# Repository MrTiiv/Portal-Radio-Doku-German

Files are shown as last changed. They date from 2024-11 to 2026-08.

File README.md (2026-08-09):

# Funktionierendes Portal Radio (Remix von [@AIBot | MyMiniFactory](https://www.myminifactory.com/object/3d-print-portal-radio-50006) (GERMAN)

## Vorwort
Zunächst ein Dank an:
- @Aibot für die Druckdateien
- [**@Astro_Flora**](https://github.com/fh190) für das Drucken von “Shell” und “Bottom” mit seinem Bambu Lab X1C 
- @monion für das Helfen mit dem Code (er ist nicht verantwortlich für den endgültigen Code ;D )
- @Chair Gaming für allgemeine Hilfe

**Hinweis: 
Hier kannst du nur meine modifizierten Teile herunterladen. Bitte lade das komplette Projekt vom Original-Autor herunter! 
[**https://www.myminifactory.com/object/3d-print-portal-radio-50006**](https://www.myminifactory.com/object/3d-print-portal-radio-50006)**
  
## Allgemeine Informationen  
Für die Elektronik habe ich mich an einer Anleitung für ein DIY-Radio von AZ-Delivery orientiert und es so angepasst, wie es für mich passt: [https://www.az-delivery.de/products/internet-radio-mit-dem-esp32](https://www.az-delivery.de/products/internet-radio-mit-dem-esp32).

Verwendete Drucker:

-   **Bambu Lab X1C und Bambu Lab A1 Mini**
-   „Shell“ und „Base“ wurden mit dem Bambu Lab X1C gedruckt, können aber auch mit dem Bambu Lab A1 gedruckt werden. Beide haben eine Druckfläche von 256x256x256 mm.
-   Kleinere Teile wurden mit dem Bambu Lab A1 Mini (Druckfläche 180x180x180 mm) gedruckt.

### Bekannte Probleme
Da dies mein erstes Projekt ist, kenne ich mich mit der verwendeten Mikroelektronik noch wenig aus. 
Ein nerviges Problem ist der DFPlayer. 
~~Beim Einschalten gibt er ein Störgeräusch von sich, bevor er den Song abspielt. Auch während des Songs ist ein leises, aber hörbares Störgeräusch vorhanden, insbesondere bei geringer Lautstärke. Bis jetzt habe ich dafür noch keine Lösung gefunden.~~
Das DFPlayer Problem wurde gelöst, die Verbindung vom PAM zum DFPlayer muss ein geschrimtes Kabel sein, damit sind die Störgeräusche um einiges leiser

~~Dreht man den Verstärker PAM8403 bis ganz an Ende zu dem Rastpunkt und wieder zurück Startet der Arduino aus unbekannten Gründen neu. Ich habe das Problem bisher noch nicht behoben und habe bisher auch noch keinen Lösungsansatz.~~
~~Das Problem mit dem Absturz ist behoben. Ich habe Kondensatoren hinzugefügt, einmal auf Plus und einmal auf Minus (siehe Schaltplan), damit ist das Problem im Augenblick behoben.~~
Die Abstürze wurden alle behoben beim entfernen des Step Up Moduls und des Kleinen Akkus, eine Powerbank hat das ganze Problem gelöst. 

## Das Portal Radio
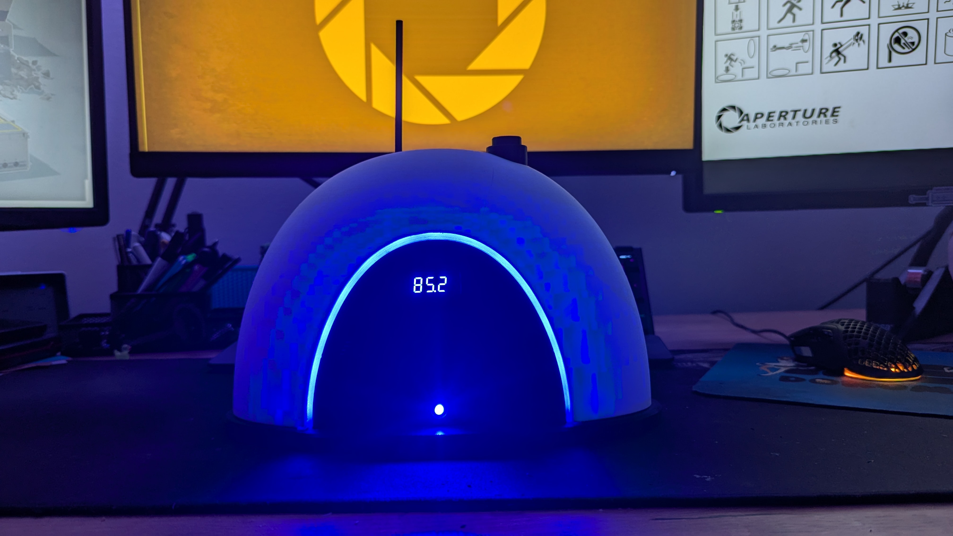
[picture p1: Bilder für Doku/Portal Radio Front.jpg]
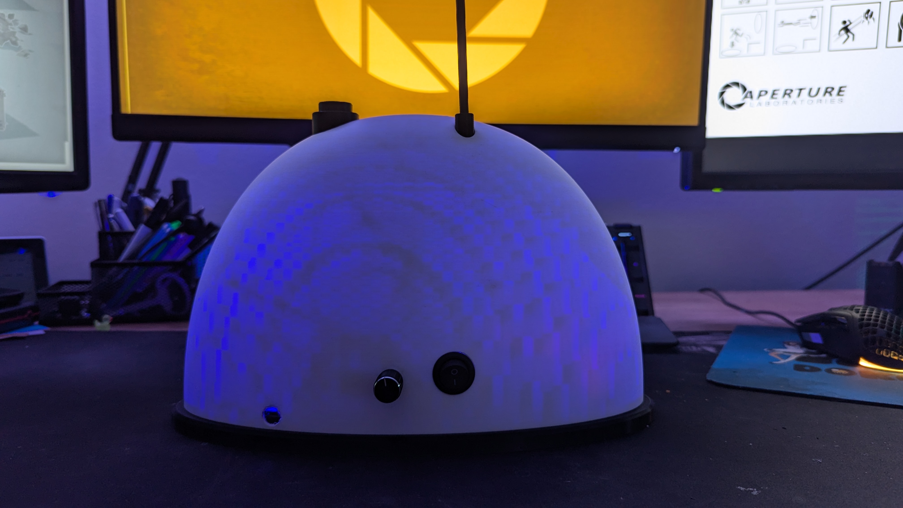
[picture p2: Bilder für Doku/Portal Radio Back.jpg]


### Funktion
  
Das Radio hat folgende Funktionen:

-   Beim Einschalten leuchten die LEDs am Ring blau auf, die 7-Segment-Anzeige zeigt eine Startup Animation und ein Startup Sound ist zu hören
-   Nach dem Einschalten leuchtet die blaue LED an der Front als Indikatior das die Musik abgespielt wird.
-   Beim Betätigen des Potis blinkt die blaue LED an der Front und es kann mithilfe des Potis eine neue "Frequenz" eingestellt werden die beim erneuten betätigen des Potis bestätigt wird.
-   Über den Drehregler oben kann die Lautstärke eingestellt werden.
  
### Teileliste
  
Hier sind die Teile, die ich für das Radio gekauft habe, eine Mischung vom Amazon und AliExpress:  
  
- [7 Segment Anzeige TM1637 Blau](https://www.amazon.de/dp/B09X1Z8CC8?ref=ppx_yo2ov_dt_b_fed_asin_title)  
- [USB Typ C Batterielademodul TP4056](https://amzn.eu/d/bJx8FN1) [¹]
- [AZ Delivery Mikrocontroller AZ-ATmega 328](https://amzn.eu/d/12fmeU2)  
- [2x AZ Delivery DFPlayer Mini 3 Watt Lautsprecher](https://amzn.eu/d/aCnC54G)  
- [5mm LED Blau](https://amzn.eu/d/fTzluys)  
- [DFPlayer Mini](https://de.aliexpress.com/item/1005006181511315.html?)  
- [PAM8403 Audio Verstärker](https://de.aliexpress.com/item/1005006135778016.html)  
- [JST XH 2 Polig Kabelstecker](https://de.aliexpress.com/item/1005006577211209.html) [²] 
- [Wippschalter Rund](https://amzn.eu/d/0qvCGKB)  
- [verwendeter Akku](https://amzn.eu/d/0gAyQbPa) 
- [~350g PLA Schwarzes Filament](https://amzn.eu/d/ibRLTVA)
- [~265g PLA Weißes Filament](https://amzn.eu/d/6HExSpr)
- [~30g PLA Durchsichtiges Filament](https://amzn.eu/d/5HmzEyD)
 -[~2g PETG Schwarzes Filament](https://amzn.eu/d/5IXwTd8)[⁴]
- Sekundenkleber (zum Ankleben der Elektronik so wie der LED's)
- Blechschrauben (zum Anschrauben der Elektronik)

[¹]: Vorsicht! mit diesem Lademodul kann man nur mit einem USB A auf USB C Kabel laden, nicht mit einem USB C - USB C Kabel.

[²]: Um den Akku und die Lautsprecher abtrennbar zu machen, habe ich die Originalen Stecker der jeweiligen Komponenten abgeschnitten und diesen angelötet, schlauer wäre gewesen gleich den richtigen Stecker zu bestellen aber egal ^^.

[⁴]: Das PETG Filament ist für das Aperture Logo vorne am Radio damit man es sieht. Man sieht es mit dem PETG Filament zwar, es kommt aber tatsächlich darauf an wie man draufschaut. Auffällig ist es nicht, also kann man dafür auch anderes Filament z.b. in einer anderen Farbe verwenden.

## 3D Druck 

### Info und Änderungen
Abgeändert habe ich das *"[front-panel](https://github.com/MrTiiv/Portal-Radio-Doku-German/blob/main/Modified%203D%20Print%20Parts/front-panel-modified-for-displayl.stl)"* damit das Display vorne reinpasst so wie den *"[top-button](https://github.com/MrTiiv/Portal-Radio-Doku-German/blob/main/Modified%203D%20Print%20Parts/top-button-modified-for-PAM8403.stl)"* damit man den Knopf oben für die Lautstärke drehen kann und das der Audio Verstärker PAM8403 da Perfekt hineinpasst. Diese Änderungen kannst du hier auf GitHub herunterladen. 
Dadurch dass ich das Display in das Radio montiert habe müssen folgende Teile die du von Aibot auf MMF herunterlädst nicht gedruckt werden:
- "ledholder-screen"
- "screen-main"
- "screen-8-top"
- "screen-8-bot"

Außerdem habe ich "electronics-mount" und "front-logo-stencil-1" nicht gedruckt. Das Front Logo habe ich so angepasst, das der Drucker das Logo mit vorne rein druckt. Aibot hat denke ich vorgesehen das man das Logo vorne Draufsprüht mit dem "front-logo-stencil-1".

### Druckereinstellungen
Die Druckeinstellungen basieren alle auf **Bambu Studio**.

-   **0,20 mm Standardprofil**, 15 % Fülldichte, Gitternetz-Füllmuster, Wandlinien: 2, Schichthöhe: 0,2 mm, keine Supports (außer für „Shell“).
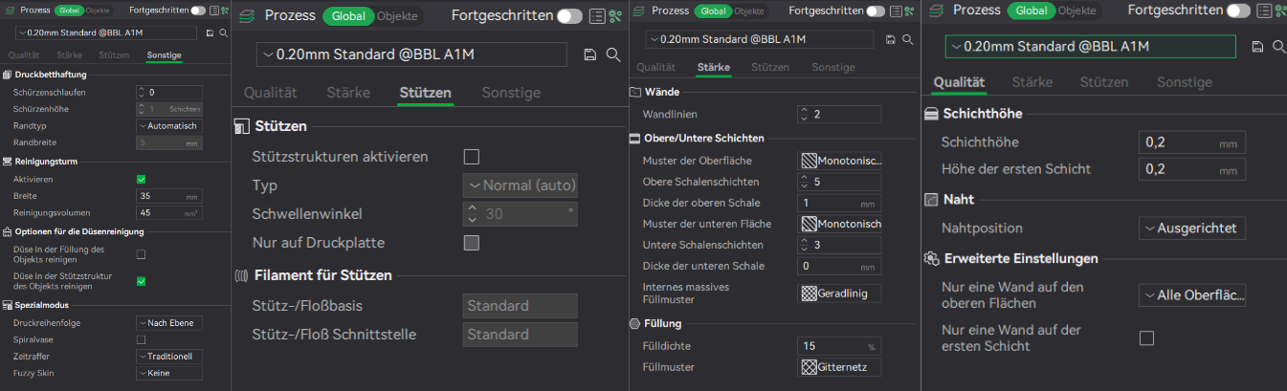
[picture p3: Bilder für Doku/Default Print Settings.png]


### Base

Für die Base habe ich "base" genommen und nicht "base-with-holes-for-electronics-mount" da ich meine eigene Elektronik eingebaut habe.
Folgende Druckeinstellungen habe ich bei der Base geändert:

- Fülldichte: 35 %, Füllmuster: Geradlinig, Wandlinien: 4 (für besseren Halt der Schrauben). 

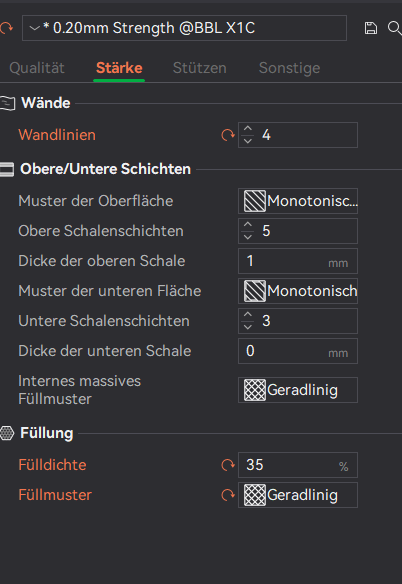
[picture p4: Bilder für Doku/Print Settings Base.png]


### Shell
Die Shell muss mit Supports gedruckt werden. Verwendet wurden die Supports "Baum". 
Bei der Druckbetthaftung habe ich die Schürzenschlaufen auf 5 und die Nahtposition auf zufällig. 

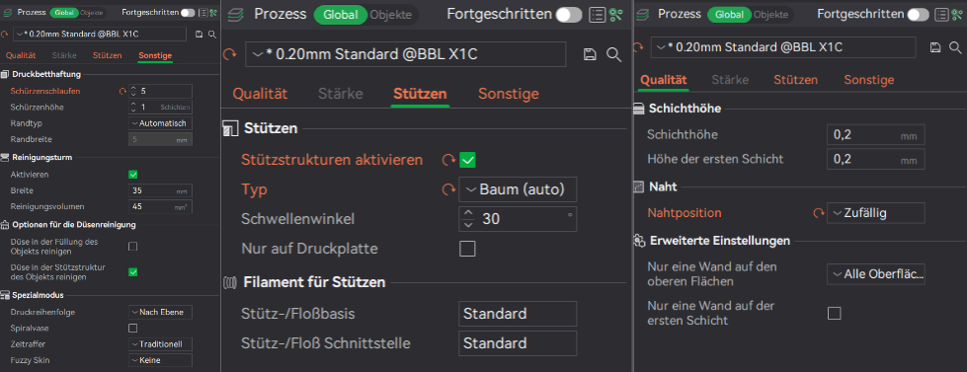
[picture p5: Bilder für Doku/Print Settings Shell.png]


### Zusammenbau
Nachdem alles gedruckt wurde sollte man 10 einzelne Teile vor sich liegen haben
- "base"
- "shell"
- "antenne-holder"
- "grill-left"
- "grill-right"
- "led-ark"
- "led-ark-diffuser"
- "led-ring"
- "[front-panel](https://github.com/MrTiiv/Portal-Radio-Doku-German/blob/main/Modified%203D%20Print%20Parts/front-panel-modified-for-displayl.stl)" (meine geänderte Version)
- "[top-button](https://github.com/MrTiiv/Portal-Radio-Doku-German/blob/main/Modified%203D%20Print%20Parts/top-button-modified-for-PAM8403.stl)" (meine geänderte Version)

An sich sollte es sich fast von selber erklären wie das Radio zusammengebaut wird. 
"base" und "shell" werden miteinander verschraubt, ich habe eine M3 Mutter in die "shell" geklebt und mit einer M3x8 Schraube verbinde ich dann "base" und "shell" auch so das es einfach wieder geöffnet werden kann.

"antenne-holder" habe ich an die "shell" angeklebt

"top-button" habe ich auch an die "shell" angeklebt

"grill-left" und "grill-right" habe ich an "front-panel" angeklebt 

"led-ring" habe ich auch an "front-panel" angeklebt

"led-ark" habe ich in die dafür vorgesehenen löcher in der "base" mit Blechschrauben eingeschraubt, nachdem ich die LED's in die "led-ark" eingeklebt hatte. Ich habe nicht alle löcher vom "led-ark" mit LED's gefüllt, ich habe nur jedes zweite Loch verwendet und es ist trotzdem hell genug. Auch habe ich erst alle LED's Parallel zusammengelötet bevor ich die ark in die Base eingeschraubt habe.

Die Löcher für den ein/aus Schalter so wie das Loch für den Poti hinten und den Ladeport habe ich je nach Position in die Shell gebohrt.. 

## Die Elektronik

### Schaltplan
Wie bereits am Anfang erwähnt, habe ich die Elektronik von einer DIY Anleitung für ein Internetradio von AZ Delivery abgeschaut. Aber bevor ich die Elektronik verdrahtet und eingebaut habe, habe ich mit der Software **Fritzing** einen Schaltplan erstellt, den ich euch hier zur Verfügung stelle. 

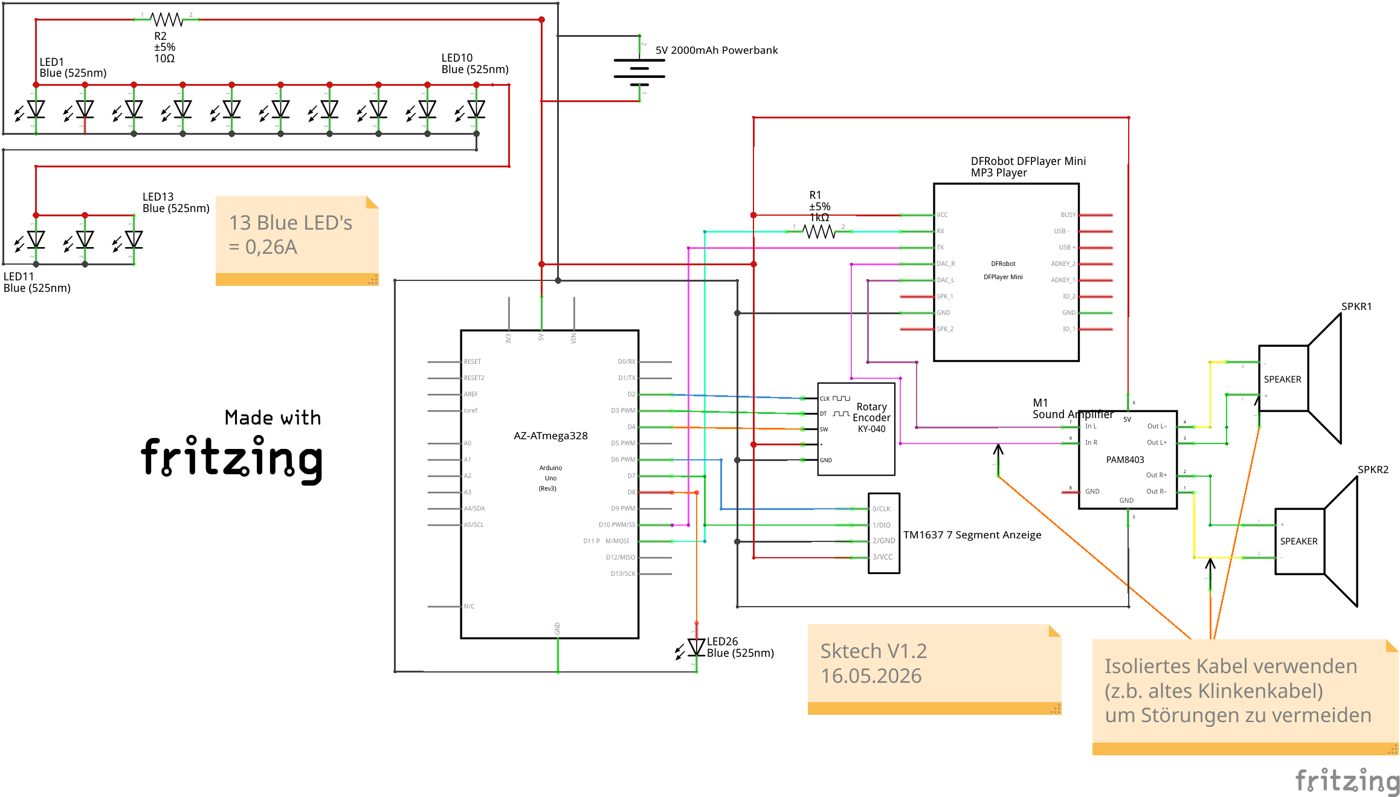
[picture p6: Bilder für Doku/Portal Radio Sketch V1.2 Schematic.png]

> VORSICHT! Bei der Programmierung des DFPlayers ist RX und TX wieso auch immer gedreht.
z.b. **`SoftwareSerial mySoftwareSerial(11, 10); // RX, TX`** funktioniert nicht du musst
 **`SoftwareSerial mySoftwareSerial(10, 11); // RX, TX`** verwenden.
Also **RX = TX** und **TX = RX** (wieso auch immer?)

Der Schaltplan ist 1:1 zu meinem jetzigen Portal Radio.
Das Step Up Module muss VOR dem einbauen eingestellt werden. Ich habe die ganze Elektronik gelötet, das Step Up Module hätte ich genauso wie den Akku und die Lautsprecher Steckbar machen sollen, falls das Modul nochmal nachgestellt werden muss. Die Spannung habe ich mit Wago 221 Klemmen verteilt, die ich auf der Base aufgeklebt habe (please don't judge me)

### Das Einbauen der Elektronik

An sich gibt es keine feste Position für die Elektronik, das muss man am Ende selbst entscheiden.

Ich habe den Charger und das Step-Up Module mit kleinen Abstandshaltern wegen den Lötpunkten an der Base mit Sekundenkleber festgeklebt.

Die LED's habe ich mit jeweils einem kleinen tropfen Sekundenkleber in den led ring geklebt.

Den Arduino habe ich auch mit einem kleinen Abstandshaltern mit Blechschrauben festgeschraubt.

Für den DFPlayer habe ich eine kleine Platte gedruckt, die etwas länger ist als der DFPlayer, um den DFPlayer mit zwei Blechschrauben zu befestigen. Die Platte hält den DFPlayer so gesehen fest.

Die 7 Segment Anzeige habe ich in das von mir geänderte Front Panel eingeschraubt.

Die Lautsprecher habe ich schräg in das Front Panel eingeschraubt damit die Membranen sogesehen durch den "grill-left" und "grill-right" hindurchschauen.

### Der Code

Dieser Code ist mein erster selber geschriebener Code für einen Arduino. Bitte teilt es mir mit falls fehler oder Optimierungen zu sehen sind.

Der Code hat folgende Funktion:

Das Radio fährt beim einschalten hoch und zeigt während des hochfahrens eine kleine Animation vorne auf der Anzeige gefolgt von einem Startup Sound.
Nachdem das hochfahren abgeschlossen ist Spielt das Radio den Standart Portal Radio Sound im loop und zeigt vorne auf der Anzeige 85.2. 
Wenn der POTI hinten am Radio betätigt wird kann eine andere "Frequenz" eingestellt werden. Wird die gewünschte Frequenz eingestellt und erneut mit dem betätigen des POTIS bestätigt Spielt das Radio einen anderen Song der vorher auf die SD Karte geladen wurde.
(Die Songs und die Nummern der Songs müssen im Code natürlich demensprechen angepasst werden. Bei der von mir Verwendeten DFPlayer Libary ist es so das die Nummer 1 der erste Song ist der auf die SDKarte geladen wurde. Nummer 2 ist der zweite Song der auf die SD Karte geladen wurde etc....)
Alles im allem ist das die Hauptaufgabe des Codes, weitere funktionen kann man sich aus den (hoffentlich verständlichen) Kommentaren des Codes entnehmen. 

AI Disclaimer:
Der Code wurde von mir  geschrieben aber AI hat mir geholfen bei den Kommentaren und bei generellen Fragen beim Schreiben des Codes.
- GitHub Copilot hat mir bei den Kommentaren geholfen
- ChatGPT hat mir beim beantworten von Fragen geholfen und bei dem Optimieren der Kommentare.
Keiner der AI Programme hat eine Zeile des Codes geschrieben.

## Schlusswort
Ich hoffe, diese Dokumentation hilft beim Nachbau des Portal Radios. Das Radio ist ein wirklicher Hingucker und das es den Radiosong abspielt, macht es noch um einiges cooler.

Fragen oder Anregungen gerne auf GitHub, Discord (MrTiiv), [Instagram](https://www.instagram.com/mrtiiv/), [Steam](https://steamcommunity.com/id/MrTiiv).

 >This was a triumph  
I'm making a note here; "Huge success"

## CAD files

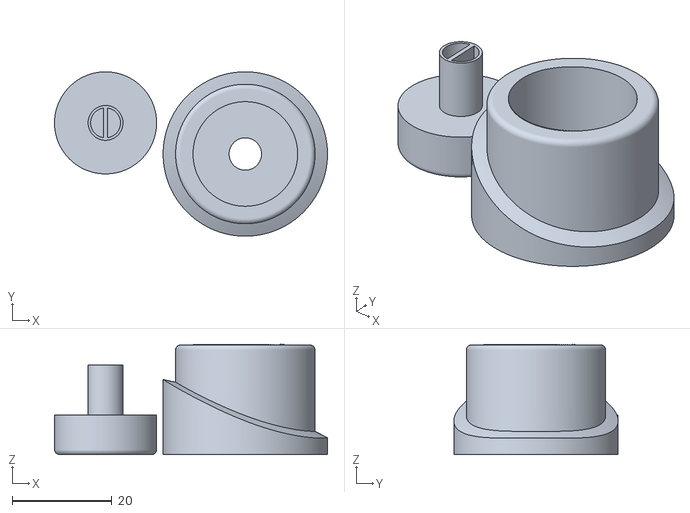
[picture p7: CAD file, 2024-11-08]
Modified 3D Print Parts/top-button-modified-for-PAM8403.stl
54.8 x 33.0 x 22.1

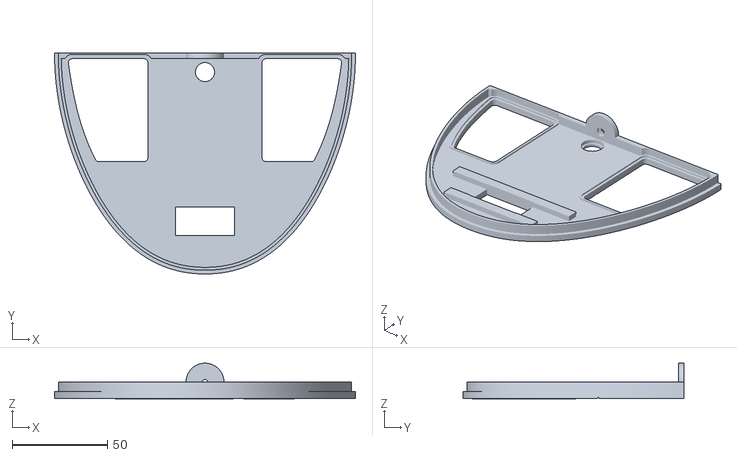
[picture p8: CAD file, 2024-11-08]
Modified 3D Print Parts/front-panel-modified-for-displayl.stl
158.0 x 116.0 x 18.7

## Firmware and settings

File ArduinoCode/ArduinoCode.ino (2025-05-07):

                                                 
 /***********************************************************************************************
 *                                                                                             *
 *    _|      _|            _|_|_|_|_|  _|  _|                                                 *
 *   _|_|  _|_|  _|  _|_|      _|              _|      _|                                      * 
 *   _|  _|  _|  _|_|          _|      _|  _|  _|      _|                                      *
 *   _|      _|  _|            _|      _|  _|    _|  _|                                        *
 *   _|      _|  _|            _|      _|  _|      _|                                          *      
 *                                                                                             *
 *                                                                                             *
 *  Project:       Working Portal Radio, plays Music from the Game                             *
 *  Author:        MrTiiv                                                                      *
 *  Year:          2025                                                                        *
 *  License:       GNU General Public License v3.0                                             *
 *                                                                                             *
 *  The corresponding circuit schematic is available on my GitHub:                             *
 *  https://github.com/MrTiiv/Portal-Radio-Doku-German                                         *
 *                                                                                             *
 *  This program is free software: you can redistribute it and/or modify                       *
 *  it under the terms of the GNU General Public License as published by                       *
 *  the Free Software Foundation, either version 3 of the License, or                          *
 *  (at your option) any later version.                                                        *
 *                                                                                             *
 *  This program is distributed in the hope that it will be useful,                            *
 *  but WITHOUT ANY WARRANTY; without even the implied warranty of                             *
 *  MERCHANTABILITY or FITNESS FOR A PARTICULAR PURPOSE. See the GNU                           *
 *  General Public License for more details.                                                   *
 *                                                                                             *
 *  You should have received a copy of the GNU General Public License                          *
 *  along with this program. If not, see <https://www.gnu.org/licenses/>.                      *
 *                                                                                             *
 *  AI Disclaimer:                                                                             *
 *  This code was written by me, MrTiiv. However, I used AI tools for assistance with the      *
 *  comments and for answering questions I had during the development process. Specifically:   *
 *    - GitHub Copilot was used to help refine and improve the comments in the code.           *
 *    - ChatGPT was used to answer questions and improve the comments in the code.             *
 *  None of the AI tools wrote any part of the code itself.                                    *
 *                                                                                             *
 ***********************************************************************************************/


// ============================
// MP3 FILE ORDER AND NAMES
// ============================
// 0001 = Aperture Science Theme
// 0002 = Portal Radio Song Decompressed
// 0003 = Portal Radio Song 8 Bit Version
// 0004 = Portal Still Alive Song
// 0005 = Portal 2 End Credits Song
// 0006 = Portal 2 Cara Mia Addio Song
// 0007 = Portal 2 OST Song 9999999
// 0008 = Aperture Desk Job Cave Jonhson
// 0009 = Portal 2 Secret SSTV Image
// 0010 = MEME SONG FLINT AND STEEL  

// ============================
// Include Required Libraries
// ============================
// Libraries required for managing the 7-segment display, serial communication and interacting with the DFPlayer mini module.
#include <TM1637.h>                 // 7-Segment Display Library
#include <SoftwareSerial.h>         // Software UART for DFPlayer Mini
#include "Arduino.h"                // Core Arduino functions
#include "DFRobotDFPlayerMini.h"    // DFPlayer Mini Library

// ============================
// DFPlayer Mini Setup
// ============================
// Initializes the software serial communication for the DFPlayer Mini module.
SoftwareSerial softSerial(/*rx =*/10, /*tx =*/11);  // RX and TX pins for software serial communication with DFPlayer
#define FPSerial softSerial
DFRobotDFPlayerMini myDFPlayer;

// ============================
// GPIO Pin Definitions
// ============================
// Define the GPIO Pins for the 7-segment display, status LED and rotary encoder.
TM1637 tm(6, 7);             // TM1637 Display: CLK = Pin 6, DIO = Pin 7
#define FRONT_LED        8   // Status LED
#define ENCODER_CLK      2   // Rotary encoder - CLK pin
#define ENCODER_DT       3   // Rotary encoder - DT pin
#define ENCODER_BUTTON   4   // Rotary encoder - Button pim

// ============================
// Global Variables
// ============================
// Storage for rotary encoder position, rotary encoder button states and debounce timing
// These variables are used to manage the rotary encoder and LED blinking behavior. 
int static rotaryNum = 0;           // Rotary Encoder Position
int static buttonPushed;            // Rotary Encoder Button press state
static bool buttonReleased = true;  // Rotary Encoder Button release detection
int static lastCLKState;            // Last CLK state for rotary encoder rotation detection
unsigned long lastDebounceTime = 0; // Millis storage for Debounce timer rotary encoder

// LED Variable: Used for blinking the FRONT_LED in "MODE_SELECT"
unsigned long millisLEDBlinkTime = 0;   

// Mode Constants: Define different modes.
int static modeNumber;                 // Active Mode Selection
int const  MODE_SELECT         = 1;    // Mode: Selection Menu
int const  MODE_DEFAULT_FREQ   = 2;    // Mode: Default frequency 85.2 
int const  MODE_FREQ_2         = 3;    // Mode: Frequency 88.1
int const  MODE_FREQ_3         = 4;    // Mode: Frequency 90.5
int const  MODE_FREQ_4         = 5;    // Mode: Frequency 92.3
int const  MODE_FREQ_5         = 6;    // Mode: Frequency 94.7
int const  MODE_FREQ_6         = 7;    // Mode: Frequency 96.8
int const  MODE_FREQ_7         = 8;    // Mode: Frequency 97.6
int const  MODE_FREQ_8         = 9;    // Mode: Frequency 99.9
int const  MODE_FREQ_9         = 10;   // Mode: Frequency 102.4

// ============================
// Setup Function
// ============================
// Initializes serial communication, GPIO pins, TM1637 display and the DFPlayer Mini module. 
void setup() {
    softSerial.begin(9600); // Start serial communication for DFPlayer Mini
    Serial.begin(115200);   // Start serial communication for debugging

    // Configure GPIO pins for output and input
    pinMode(FRONT_LED, OUTPUT);
    pinMode(ENCODER_CLK, INPUT);
    pinMode(ENCODER_DT, INPUT);
    pinMode(ENCODER_BUTTON, INPUT);

    // Initialize TM1637 Display
    tm.begin();
    tm.setBrightnessPercent(90);    // Set display brightness
    tm.display("     ");            // Clear Display on Startup

    // Read initial state of the rotary encoder
    lastCLKState = digitalRead(ENCODER_CLK);

    // Initialize DFPlayer Mini
     if (!myDFPlayer.begin(FPSerial, /*isACK = */true, /*doReset = */true)) {  
     }
    myDFPlayer.volume(30);  // Set DFPlayer volume
    myDFPlayer.play(1);     // Play startup track

    startup();      // Run startup animation
}

// ============================
// Startup Animation
// ============================
// Simulates radio scanning effect on the 7-segment display.
// The display shows random numbers before settling on the default frequency
// Plays the Aperture Science Theme during startup
void startup() {
    String strRandNumber1;      // First part of the random number
    String strRandNumber2;      // Second part of the random number

    for (unsigned counter = 0; counter < 1000; ++counter) {
        // Random Numbers 4-Digits
        if (counter < 50) { 
            strRandNumber1 = random(99);
            strRandNumber2 = random(99);
            String strNum1Num2 = strRandNumber1 + "." + strRandNumber2;
            tm.display(strNum1Num2);
            delay(50);
            continue;
        }
        // Random Numbers 3-Digitls
        else if (counter < 100) { 
            strRandNumber1 = random(99);
            strRandNumber2 = random(9);
            String strNum1Num2 = strRandNumber1 + "." + strRandNumber2 + " ";
            tm.display(strNum1Num2);
            delay(50);
            continue;
        }
        else{
            tm.display("85.2"); // Final display after animation
        }
    }

    modeNumber = MODE_DEFAULT_FREQ;  // Set default mode
    myDFPlayer.loop(2);              // Start looping track 2 after startup
}

// ============================
// Main Loop Function
// ============================
// Continuously checks the current mode and executes the appropriate function.
// Blinks the LED in "MODE_SELECT" mode.
void loop() {
    switch(modeNumber) {
        case MODE_SELECT:          Select();        break;
        case MODE_DEFAULT_FREQ:    DefaultFreq();   break;
        case MODE_FREQ_2:          Freq_2();        break;
        case MODE_FREQ_3:          Freq_3();        break;
        case MODE_FREQ_4:          Freq_4();        break;
        case MODE_FREQ_5:          Freq_5();        break;
        case MODE_FREQ_6:          Freq_6();        break;
        case MODE_FREQ_7:          Freq_7();        break;
        case MODE_FREQ_8:          Freq_8();        break;
        case MODE_FREQ_9:          Freq_9();        break;
    }

    // Blink LED when in MODE_SELECTion mode
    const int MODE_SELECTorLEDBlink = 250; // LED Blink Speed
    if(modeNumber == MODE_SELECT) {
        if(millis() - millisLEDBlinkTime > MODE_SELECTorLEDBlink) {
            if(digitalRead(FRONT_LED) == LOW) {
                digitalWrite(FRONT_LED, HIGH);
            }
            else{
                digitalWrite(FRONT_LED, LOW);
            }
            millisLEDBlinkTime = millis();
        }
    }
}

// ============================
// Rotary Encoder Logic
// ============================
// Reads encoder states to detect rotation direction and updates mode selection.
void RotaryEncoder() {
    int intCurrentCLKState = digitalRead(ENCODER_CLK);
    int intCurrentDTState = digitalRead(ENCODER_DT);
    const int constDebounceDelay = 2; // Debounce delay in millisecond 

    if (intCurrentCLKState != lastCLKState) {
        if (millis() - lastDebounceTime > constDebounceDelay ) {
            // Determine direction of encoder rotation
            if (intCurrentCLKState == LOW && intCurrentDTState != intCurrentCLKState) {
                rotaryNum++; // Clockwise rotation
            }
                else if (intCurrentCLKState == LOW && intCurrentDTState == intCurrentCLKState) {
                rotaryNum--; //Counter-clockwise rotation
                }
        }
        lastDebounceTime = millis();
    }
    lastCLKState = intCurrentCLKState;

    // Wrap-around for rotary encoder position
    if (rotaryNum < 0) {
        rotaryNum = 8;
    }
    else if (rotaryNum > 8) {
        rotaryNum = 0;
    }
}

// ============================
// Mode Selection Menu
// ============================
// Allows the user to select the desired radio frequency using the rotary encoder.
// Updated the mode and starts playing the corresponding track
void Select() {
    buttonPushed = digitalRead(ENCODER_BUTTON);
    if(buttonReleased && buttonPushed == HIGH){
        buttonReleased = false;
    }

    // Display the frequency and handle button press to select the mode
    switch(rotaryNum) {
        case 0:
            tm.display("85.2 ");        // Display selected frequency
                if((buttonPushed == LOW) && (!buttonReleased)){
                modeNumber = MODE_DEFAULT_FREQ;
                myDFPlayer.loop(2);     // Loop selected Song
                buttonReleased = true;
            }
            break;
        case 1:
            tm.display("88.1 ");        // Display selected frequency
            if((buttonPushed == LOW) && (!buttonReleased)){
                modeNumber = MODE_FREQ_2;
                myDFPlayer.loop(3);     // Loop selected Song
                buttonReleased = true;
            }
            break;
        case 2:
            tm.display("90.5 ");        // Display selected frequency
            if((buttonPushed == LOW) && (!buttonReleased)){
                modeNumber = MODE_FREQ_3;
                myDFPlayer.loop(4);     // Loop selected Song
                buttonReleased = true;
            }
            break;
        case 3:
            tm.display("92.3 ");        // Display selected frequency
            if((buttonPushed == LOW) && (!buttonReleased)){
                modeNumber = MODE_FREQ_4;
                myDFPlayer.loop(5);     // Loop selected Song
                buttonReleased = true;
            }
            break;
        case 4:
            tm.display("94.7 ");        // Display selected frequency
            if((buttonPushed == LOW) && (!buttonReleased)){
                modeNumber = MODE_FREQ_5;
                myDFPlayer.loop(6);     // Loop selected Song
                buttonReleased = true;
            }
            break;
        case 5:
            tm.display("96.8 ");        // Display selected frequency
            if((buttonPushed == LOW) && (!buttonReleased)){
                modeNumber = MODE_FREQ_6;
                myDFPlayer.loop(9);     // Loop selected Song
                buttonReleased = true;
            }
            break;
        case 6:
            tm.display("97.6 ");        // Display selected frequency
            if((buttonPushed == LOW) && (!buttonReleased)){
                modeNumber = MODE_FREQ_7;
                myDFPlayer.loop(8);     // Loop selected Song
                buttonReleased = true;
            }
            break;
        case 7:
            tm.display("99.9 ");        // Display selected frequency
                if((buttonPushed == LOW) && (!buttonReleased)){
                modeNumber = MODE_FREQ_8;
                myDFPlayer.loop(7);     // Loop selected Song
                buttonReleased = true;
            }
            break;
        case 8:
            tm.display("102.4");        // Display selected frequency
            if((buttonPushed == LOW) && (!buttonReleased)){
                modeNumber = MODE_FREQ_9;
                myDFPlayer.loop(10);    // Loop selected Song
                buttonReleased = true;
            }
            break;

        // If case is unknown, Display 8888
        default:
            tm.display("8888");
            break;
    }

    // Check for rotary movement
    RotaryEncoder(); 
}

// ============================
// Frequency Modes
// ============================
// These functions represent each of the frequency modes.
// Each frequency is displayed on the 7-segment display, and the corresponding track is played on the DFPlayer Mini.
// The LED stays on during playback, and pressing the encoder button stops the playback, returning to the Selection Mode. 

void DefaultFreq() {
    buttonPushed = digitalRead(ENCODER_BUTTON);
        digitalWrite(FRONT_LED, HIGH);  // Turn on LED
        tm.display("85.2 ");            // Display current frequency      
    if(buttonReleased && buttonPushed == HIGH) {
        buttonReleased = false;
    }
    if(!buttonReleased && buttonPushed == LOW) {
        modeNumber = MODE_SELECT;
        buttonReleased = true;
        digitalWrite(FRONT_LED, LOW);   // Turn off LED
        myDFPlayer.stop();              // Stop the DFPlayer
    }
}
void Freq_2() {
    buttonPushed = digitalRead(ENCODER_BUTTON);
        digitalWrite(FRONT_LED, HIGH);  // Turn off LED
        tm.display("88.1 ");            // Display current frequency
    if(buttonReleased && buttonPushed == HIGH) {
        buttonReleased = false;
    }
    if(!buttonReleased && buttonPushed == LOW) {
        modeNumber = MODE_SELECT;
        buttonReleased = true;
        digitalWrite(FRONT_LED, LOW);   // Turn off LED
        myDFPlayer.stop();              // Stop the DFPlayer
    } 
}
void Freq_3() {
    buttonPushed = digitalRead(ENCODER_BUTTON);
        digitalWrite(FRONT_LED, HIGH);  // Turn on LED
        tm.display("90.5 ");            // Display current frequency
    if(buttonReleased && buttonPushed == HIGH) {
        buttonReleased = false;
    }
    if(!buttonReleased && buttonPushed == LOW) {
        modeNumber = MODE_SELECT;
        buttonReleased = true;
        digitalWrite(FRONT_LED, LOW);   // Turn off LED
        myDFPlayer.stop();              // Stop the DFPlayer
    }
}
void Freq_4() {
    buttonPushed = digitalRead(ENCODER_BUTTON);
        digitalWrite(FRONT_LED, HIGH);  // Turn on LED
        tm.display("92.3 ");            // Display current frequency
    if(buttonReleased && buttonPushed == HIGH) {
        buttonReleased = false;
    }
    if(!buttonReleased && buttonPushed == LOW) {
        modeNumber = MODE_SELECT;
        buttonReleased = true;
        digitalWrite(FRONT_LED, LOW);   // Turn off LED
        myDFPlayer.stop();              // Stop the DFPlayer
    }
}
void Freq_5() {
    buttonPushed = digitalRead(ENCODER_BUTTON);
        digitalWrite(FRONT_LED, HIGH);  // Turn on LED
        tm.display("94.7 ");            // Display current frequency
    if(buttonReleased && buttonPushed == HIGH) {
        buttonReleased = false;
    }
    if(!buttonReleased && buttonPushed == LOW) {
        modeNumber = MODE_SELECT;
        buttonReleased = true;
        digitalWrite(FRONT_LED, LOW);   // Turn off LED
        myDFPlayer.stop();              // Stop the DFPlayer
    }
}
void Freq_6() {
    buttonPushed = digitalRead(ENCODER_BUTTON);
        digitalWrite(FRONT_LED, HIGH);  // Turn on LED
        tm.display("96.8 ");            // Display current frequency
    if(buttonReleased && buttonPushed == HIGH) {
        buttonReleased = false;
    }
    if(!buttonReleased && buttonPushed == LOW) {
        modeNumber = MODE_SELECT;
        buttonReleased = true;
        digitalWrite(FRONT_LED, LOW);   // Turn off LED
        myDFPlayer.stop();              // Stop the DFPlayer
    }
}
void Freq_7() {
    buttonPushed = digitalRead(ENCODER_BUTTON);
        digitalWrite(FRONT_LED, HIGH);  // Turn on LED
        tm.display("97.6 ");            // Display current frequency
    if(buttonReleased && buttonPushed == HIGH) {
        buttonReleased = false;
    }
    if(!buttonReleased && buttonPushed == LOW) {
        modeNumber = MODE_SELECT;
        buttonReleased = true;
        digitalWrite(FRONT_LED, LOW);   // Turn off LED
        myDFPlayer.stop();              // Stop the DFPlayer
    }
}
void Freq_8() {
    buttonPushed = digitalRead(ENCODER_BUTTON);
        digitalWrite(FRONT_LED, HIGH);  // Turn on LED
        tm.display("99.9 ");            // Display current frequency
    if(buttonReleased && buttonPushed == HIGH) {
        buttonReleased = false;
    }
    if(!buttonReleased && buttonPushed == LOW) {
        modeNumber = MODE_SELECT;
        buttonReleased = true;
        digitalWrite(FRONT_LED, LOW);   // Turn off LED
        myDFPlayer.stop();              // Stop the DFPlayer
    }
}
void Freq_9() {
    buttonPushed = digitalRead(ENCODER_BUTTON);
        digitalWrite(FRONT_LED, HIGH);  // Turn on LED
        tm.display("102.4");            // Display current frequency
    if(buttonReleased && buttonPushed == HIGH) {
        buttonReleased = false;
    }
    if(!buttonReleased && buttonPushed == LOW) {
        modeNumber = MODE_SELECT;
        buttonReleased = true;
        digitalWrite(FRONT_LED, LOW);   // Turn off LED
        myDFPlayer.stop();              // Stop the DFPlayer
    }  
}


//                .,-:;//;:=,
//            . :H@@@MM@M#H/.,+%;,
//         ,/X+ +M@@M@MM%=,-%HMMM@X/,            
//       -+@MM; $M@@MH+-,;XMMMM@MMMM@+-          
//      ;@M@@M- XM@X;. -+XXXXXHHH@M@M#@/.         
//    ,%MM@@MH ,@%=             .---=-=:=,.    
//    =@#@@@MX.,                -%HX$$%%%:;       
//   =-./@M@M$                   .;@MMMM@MM:
//   X@/ -$MM/                    . +MM@@@M$
//  ,@M@H: :@:                    . =X#@@@@-
//  ,@@@MMX, .                    /H- ;@M@M=
//  .H@@@@M@+,                    %MM+..%#$.
//   /MMMM@MMH/.                  XM@MH; =;
//   /%+%$XHH@$=              , .H@@@@MX,
//     .=--------.           -%H.,@@@@@MX,
//     .%MM@@@HHHXX$$$%+- .:$MMX =M@@MM%.
//       =XMMM@MM@MM#H;,-+HMM@M+ /MMMX=
//         =%@M@M#@$-.=$@MM@@@M; %M%=
//           ,:+$+-,/H#MMMMMMM@= =,
//                 =++%%%%+/:-.

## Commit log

2024-11-04 Portal Radio Sketch V0.1 Schematic
    Elektrischer Schalplan der Elektronik des Portal Radios
2024-11-04 Update Portal Radio Sketch V0.1 Schematic.png
2024-11-08 Screenshot Print Settings
2024-11-08 Modified 3D Print parts
    [front-panel-modified-for-displayl.stl, top-button-modified-for-PAM8403.stl]
2025-05-07 Changes because of the Finished Arduino Code
    Uploaded Code an Changed the circuit diagram
2025-05-08 Updated circuit diagram
2025-05-08 Update Readme because of Circuit Diagram Change
2025-11-16 Revise README for Portal Radio project status
    Updated README to reflect the current status of Portal Radio.
2026-07-23 Revise README with updates on issues and components
    Updated known issues and solutions for DFPlayer and Arduino restarts. Revised component list and schematic image.
